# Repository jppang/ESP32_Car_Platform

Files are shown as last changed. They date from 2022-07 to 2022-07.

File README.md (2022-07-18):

# ESP32_Car_Platform
To design a four wheels Mecanum car platform controlled by Dabble App in Arduino and MicroPython.



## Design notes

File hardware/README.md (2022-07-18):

Hardware design of this ESP32 car platform is by using KiCad 6.



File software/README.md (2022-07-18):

To control the ESP32 Car, two methods are implemented, Arduino and MicroPython.

The implementation in Arduino is forked from one repo in the Net, communicates with one APP called Dabble.
https://www.instructables.com/ESP32-Mecanum-Wheels-Robot-and-Bluetooth-Gamepad-C/

The implementation in MicroPython is coded by myself based on the above example.

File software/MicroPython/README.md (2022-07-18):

MicroPython implementation is coded by myself by referencing Arduino example.

Basically, two files are needed, ble.py and main.py.

ble.py is the MicroPython library based on ubluetooth.

main.py is the controller code.

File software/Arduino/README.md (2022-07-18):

This file is basically a forked one, and just modified those pin assignments.

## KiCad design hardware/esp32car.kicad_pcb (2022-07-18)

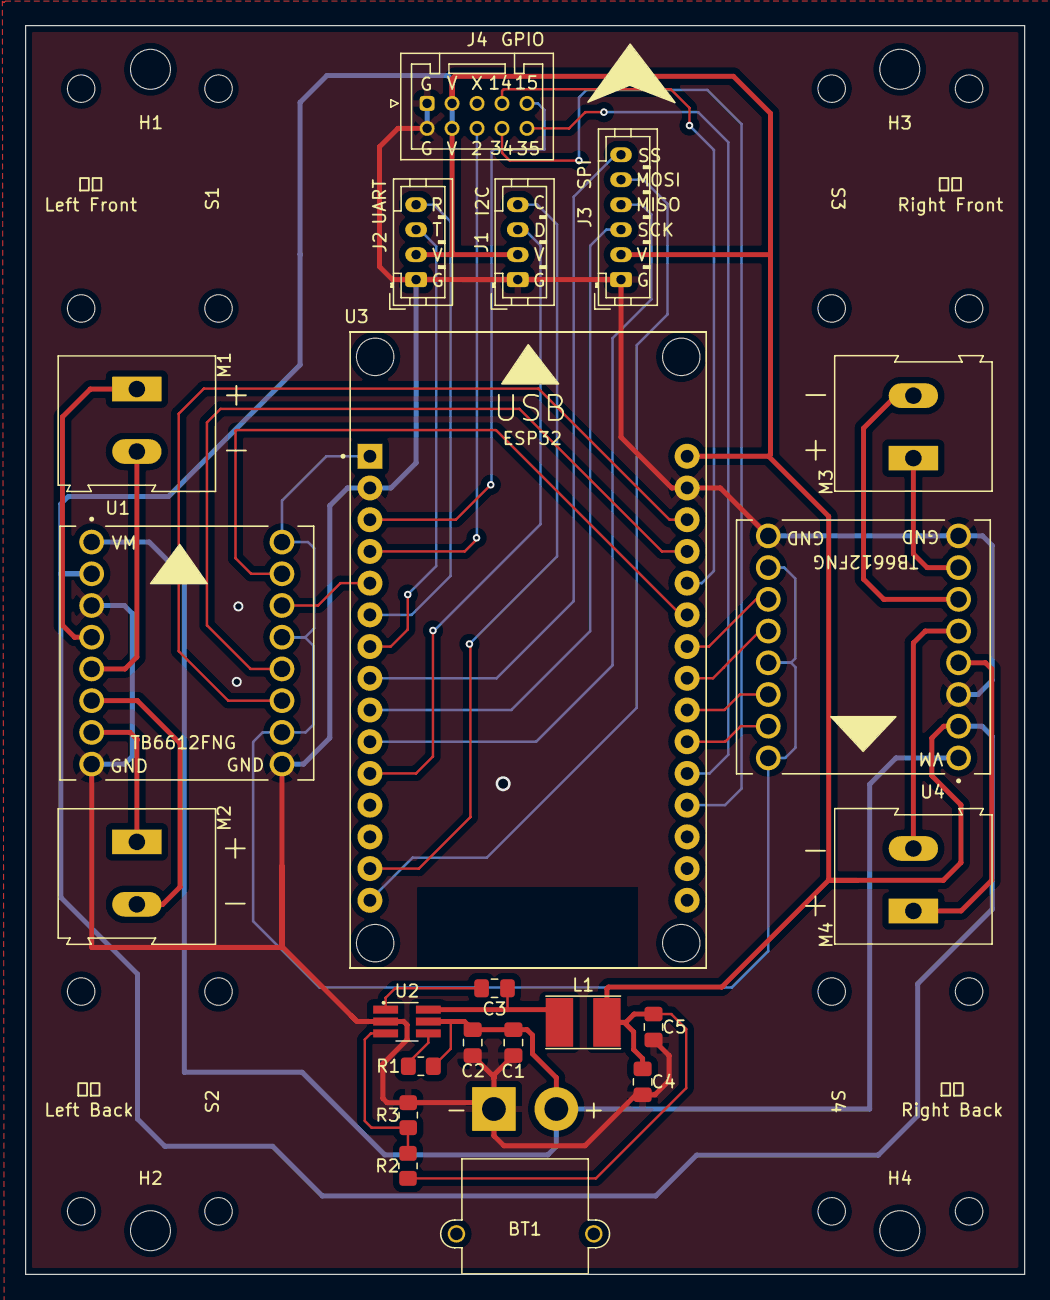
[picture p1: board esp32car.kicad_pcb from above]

Board: 2 copper layers, 80.0 x 100.0 mm, 30 parts (0 on the bottom side), 37 nets.

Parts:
BT1: 2or3S; AMASS_XT30PW-M_1x02_P2.50mm_Horizontal
C1, C5: 22uF; C_0805_2012Metric_Pad1.18x1.45mm_HandSolder
C2, C3, C4: 0.1uF; C_0805_2012Metric_Pad1.18x1.45mm_HandSolder
H1, H2, H3, H4: MountingHole; MountingHole_3.2mm_M3
J1: I2C; JST_PH_B4B-PH-K_1x04_P2.00mm_Vertical
J2: UART; JST_PH_B4B-PH-K_1x04_P2.00mm_Vertical
J3: SPI; JST_PH_B6B-PH-K_1x06_P2.00mm_Vertical
J4: GPIO; JST_PUD_B10B-PUDSS_2x05_P2.00mm_Vertical
L1: 3.3uH; L_Taiyo-Yuden_NR-40xx_HandSoldering
M1: LeftFront; TerminalBlock_Altech_AK300-2_P5.00mm
M2: LeftBack; TerminalBlock_Altech_AK300-2_P5.00mm
M3: RightFront; TerminalBlock_Altech_AK300-2_P5.00mm
M4: RightBack; TerminalBlock_Altech_AK300-2_P5.00mm
R1: 200K; R_0805_2012Metric_Pad1.20x1.40mm_HandSolder
R2: 24.6K; R_0805_2012Metric_Pad1.20x1.40mm_HandSolder
R3: 4.7K; R_0805_2012Metric_Pad1.20x1.40mm_HandSolder
S1, S2, S3, S4: Mounting_Jack_N20_Motor; MountingHole_N20_Motor_2.2mm_M2
U1: TB6612FNG-Left; MODULE_ROB-14450
U2: PW2312; TSOT-23-6_HandSoldering
U3: ESP32-DEVKIT-V1; MODULE_ESP32_DEVKIT_V1
U4: TB6612FNG-Right; MODULE_ROB-14450

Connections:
+3V3: U1.10 (PWMB), U1.13 (STBY), U1.16 (PWMA), U3.1 (3V3), U4.10 (PWMB), U4.13 (STBY), U4.16 (PWMA)
+5V: C4.1, C5.1, J1.2, J2.2, J3.2, J4.3, J4.4, L1.2, R2.1, U1.2 (VCC), U3.30 (VIN), U4.2 (VCC)
+BATT: BT1.2 (+), C1.1, C2.1, R1.1, U1.1 (VM), U2.5 (VIN), U4.1 (VM)
/2: J4.6, U3.4 (D2)
/14: J4.7, U3.26 (D14)
/15: J4.9, U3.3 (D15)
/34: J4.8, U3.19 (D34)
/35: J4.10, U3.20 (D35)
/LBBWD: U1.11 (BI2), U3.28 (D13)
/LBFWD: U1.12 (BI1), U3.27 (D12)
/LFBWD: U1.15 (AI2), U3.25 (D27)
/LFFWD: U1.14 (AI1), U3.5 (D4)
/LeftBackBWD: M2.2 (-), U1.6 (B02)
/LeftBackFWD: M2.1 (+), U1.7 (B01)
/LeftFrontBWD: M1.2 (-), U1.5 (A02)
/LeftFrontFWD: M1.1 (+), U1.4 (A01)
/MISO: J3.4, U3.10 (D19)
/MOSI: J3.5, U3.15 (D23)
/RBBWD: U3.21 (D32), U4.15 (AI2)
/RBFWD: U3.22 (D33), U4.14 (AI1)
/RFBWD: U3.24 (D26), U4.11 (BI2)
/RFFWD: U3.23 (D25), U4.12 (BI1)
/RX: J2.4, U3.6 (RX2)
/RightBackBWD: M4.2 (-), U4.5 (A02)
/RightBackFWD: M4.1 (+), U4.4 (A01)
/RightFrontBWD: M3.2 (-), U4.6 (B02)
/RightFrontFWD: M3.1 (+), U4.7 (B01)
/SCK: J3.3, U3.9 (D18)
/SCL: J1.4, U3.14 (D22)
/SDA: J1.3, U3.11 (D21)
/SS: J3.6, U3.8 (D5)
/TX: J2.3, U3.7 (TX2)
GND: BT1.1 (-), C1.2, C2.2, C4.2, C5.2, J1.1, J2.1, J3.1, J4.1, J4.2, R3.2, U1.3 (GND), U1.8 (GND), U1.9 (GND), U2.2 (GND), U3.2 (GND), U3.29 (GND), U4.3 (GND), U4.8 (GND), U4.9 (GND)
unnamed: C3.1, U2.1 (BS)
unnamed: C3.2, L1.1, U2.6 (SW)
unnamed: R1.2, U2.4 (EN)
unnamed: R2.2, R3.1, U2.3 (FB)

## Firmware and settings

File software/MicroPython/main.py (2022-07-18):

from machine import Pin
from ble import BLE

RightFrontFWD = 26
RightFrontBWD = 25
RightBackFWD = 32
RightBackBWD = 33

LeftFrontFWD = 4
LeftFrontBWD = 27
LeftBackFWD = 12
LeftBackBWD = 13

#Dabble App message is consisted of 8 bytes, and those commands associated with GamePad are in the combination of
#6th and 7th bytes of this message.
UP = b'\x00\x01'
DOWN = b'\x00\x02'
LEFT = b'\x00\x04'
RIGHT = b'\x00\x08'
TRIANGLE = b'\x04\x00'
CROSS = b'\x10\x00'
SQUARE = b' \x00'
CIRCLE = b'\x08\x00'
SELECT = b'\x02\x00'
START = b'\x01\x00'

mode = bytearray()

rfFWD = Pin(RightFrontFWD, Pin.OUT)
rfBWD = Pin(RightFrontBWD, Pin.OUT)
rbFWD = Pin(RightBackFWD, Pin.OUT)
rbBWD = Pin(RightBackBWD, Pin.OUT)
lfFWD = Pin(LeftFrontFWD, Pin.OUT)
lfBWD = Pin(LeftFrontBWD, Pin.OUT)
lbFWD = Pin(LeftBackFWD, Pin.OUT)
lbBWD = Pin(LeftBackBWD, Pin.OUT)

def moveForward():
    rfFWD.on()
    rfBWD.off()
    rbFWD.on()
    rbBWD.off()

    lfFWD.on()
    lfBWD.off()
    lbFWD.on()
    lbBWD.off()

def moveBackward():
    rfFWD.off()
    rfBWD.on()
    rbFWD.off()
    rbBWD.on()

    lfFWD.off()
    lfBWD.on()
    lbFWD.off()
    lbBWD.on()

def rotateRight():
    rfFWD.off()
    rfBWD.on()
    rbFWD.off()
    rbBWD.on()

    lfFWD.on()
    lfBWD.off()
    lbFWD.on()
    lbBWD.off()

def rotateLeft():
    rfFWD.on()
    rfBWD.off()
    rbFWD.on()
    rbBWD.off()

    lfFWD.off()
    lfBWD.on()
    lbFWD.off()
    lbBWD.on()

def moveSidewaysRight():
    rfFWD.off()
    rfBWD.on()
    rbFWD.on()
    rbBWD.off()

    lfFWD.on()
    lfBWD.off()
    lbFWD.off()
    lbBWD.on()

def moveSidewaysLeft():
    rfFWD.on()
    rfBWD.off()
    rbFWD.off()
    rbBWD.on()

    lfFWD.off()
    lfBWD.on()
    lbFWD.on()
    lbBWD.off()

def moveRightForward():
    rfFWD.off()
    rfBWD.off()
    rbFWD.on()
    rbBWD.off()

    lfFWD.on()
    lfBWD.off()
    lbFWD.off()
    lbBWD.off()

def moveLeftForward():
    rfFWD.on()
    rfBWD.off()
    rbFWD.off()
    rbBWD.off()

    lfFWD.off()
    lfBWD.off()
    lbFWD.on()
    lbBWD.off()

def stopMoving():
    rfFWD.off()
    rfBWD.off()
    rbFWD.off()
    rbBWD.off()

    lfFWD.off()
    lfBWD.off()
    lbFWD.off()
    lbBWD.off()

ble = BLE()

while(True):
    if ble.flag == True:
        mode = ble.message[5:7]
        print(mode)
        ble.flag = False

        if mode == UP:
            print("UP is pressed.")
            moveForward()
        elif mode == DOWN:
            print("DOWN is pressed.")
            moveBackward()
        elif mode == LEFT:
            print("LEFT is pressed.")
            rotateLeft()
        elif mode == RIGHT:
            print("RIGHT is pressed.")
            rotateRight()
        elif mode == TRIANGLE:
            print("TRIANGLE is pressed.")
            moveLeftForward()
        elif mode == CROSS:
            print("CROSS is pressed.")
            moveRightForward()
        elif mode == SQUARE:
            print("SQUARE is pressed.")
            moveSidewaysLeft()
        elif mode == CIRCLE:
            print("CIRCLE is pressed.")
            moveSidewaysRight()
        elif mode == SELECT:
            print("SELECT is pressed.")
        elif mode == START:
            print("START is pressed.")
        else:
            stopMoving()

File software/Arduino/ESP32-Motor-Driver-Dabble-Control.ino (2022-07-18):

#define CUSTOM_SETTINGS
#define INCLUDE_GAMEPAD_MODULE
#include <DabbleESP32.h>

#include <Arduino.h>

#define RightFrontFWD 26
#define RightFrontBWD 25
#define RightBackFWD 32
#define RightBackBWD 33

#define LeftFrontFWD 4
#define LeftFrontBWD 27
#define LeftBackFWD 12
#define LeftBackBWD 13

void setup() {
  pinMode(RightFrontFWD, OUTPUT);
  pinMode(RightFrontBWD, OUTPUT);
  pinMode(RightBackFWD, OUTPUT);
  pinMode(RightBackBWD, OUTPUT);
  pinMode(LeftFrontFWD, OUTPUT);
  pinMode(LeftFrontBWD, OUTPUT);
  pinMode(LeftBackFWD, OUTPUT);
  pinMode(LeftBackBWD, OUTPUT);
  // put your setup code here, to run once:
  Serial.begin(115200);      // make sure your Serial Monitor is also set at this baud rate.
  Dabble.begin("MyEsp32");       //set bluetooth name of your device
}

void loop() {
  Dabble.processInput();//this function is used to refresh data obtained from smartphone.Hence calling this function is mandatory in order to get data properly from your mobile.
  Serial.print("KeyPressed: ");
  if (GamePad.isUpPressed())
  {
    Serial.print("Up");
    moveForward();
  } else if (GamePad.isDownPressed())
  {
    Serial.print("Down");
    moveBackward();
  } else if (GamePad.isLeftPressed())
  {
    Serial.print("Left");
    rotateLeft();
  } else if (GamePad.isRightPressed())
  {
    Serial.print("Right");
    rotateRight();
  } else if (GamePad.isSquarePressed())
  {
    Serial.print("Square");
    moveSidewaysRight();
  } else if (GamePad.isCirclePressed())
  {
    Serial.print("Circle");
    moveSidewaysLeft();
  } else if (GamePad.isCrossPressed())
  {
    Serial.print("Cross");
    moveRightForward();
  } else if (GamePad.isTrianglePressed())
  {
    Serial.print("Triangle");
    moveLeftForward();
  } else
  {
    stopMoving();
  }

  /*if (GamePad.isStartPressed())
    {
    Serial.print("Start");
    }

    if (GamePad.isSelectPressed())
    {
    Serial.print("Select");
    } */
  Serial.print('\t');

  int a = GamePad.getAngle();
  Serial.print("Angle: ");
  Serial.print(a);
  Serial.print('\t');
  int b = GamePad.getRadius();
  Serial.print("Radius: ");
  Serial.print(b);
  Serial.print('\t');
  float c = GamePad.getXaxisData();
  Serial.print("x_axis: ");
  Serial.print(c);
  Serial.print('\t');
  float d = GamePad.getYaxisData();
  Serial.print("y_axis: ");
  Serial.println(d);
  Serial.println();
}

void moveForward() {
  digitalWrite(RightFrontFWD, HIGH);
  digitalWrite(RightFrontBWD, LOW);
  digitalWrite(RightBackFWD, HIGH);
  digitalWrite(RightBackBWD, LOW);

  digitalWrite(LeftFrontFWD, HIGH);
  digitalWrite(LeftFrontBWD, LOW);
  digitalWrite(LeftBackFWD, HIGH);
  digitalWrite(LeftBackBWD, LOW);
}

void moveBackward() {
  digitalWrite(RightFrontFWD, LOW);
  digitalWrite(RightFrontBWD, HIGH);
  digitalWrite(RightBackFWD, LOW);
  digitalWrite(RightBackBWD, HIGH);

  digitalWrite(LeftFrontFWD, LOW);
  digitalWrite(LeftFrontBWD, HIGH);
  digitalWrite(LeftBackFWD, LOW);
  digitalWrite(LeftBackBWD, HIGH);
}

void rotateRight() {
  digitalWrite(RightFrontFWD, LOW);
  digitalWrite(RightFrontBWD, HIGH);
  digitalWrite(RightBackFWD, LOW);
  digitalWrite(RightBackBWD, HIGH);

  digitalWrite(LeftFrontFWD, HIGH);
  digitalWrite(LeftFrontBWD, LOW);
  digitalWrite(LeftBackFWD, HIGH);
  digitalWrite(LeftBackBWD, LOW);
}

void rotateLeft() {
  digitalWrite(RightFrontFWD, HIGH);
  digitalWrite(RightFrontBWD, LOW);
  digitalWrite(RightBackFWD, HIGH);
  digitalWrite(RightBackBWD, LOW);

  digitalWrite(LeftFrontFWD, LOW);
  digitalWrite(LeftFrontBWD, HIGH);
  digitalWrite(LeftBackFWD, LOW);
  digitalWrite(LeftBackBWD, HIGH);
}

void moveSidewaysRight() {
  digitalWrite(RightFrontFWD, LOW);
  digitalWrite(RightFrontBWD, HIGH);
  digitalWrite(RightBackFWD, HIGH);
  digitalWrite(RightBackBWD, LOW);

  digitalWrite(LeftFrontFWD, HIGH);
  digitalWrite(LeftFrontBWD, LOW);
  digitalWrite(LeftBackFWD, LOW);
  digitalWrite(LeftBackBWD, HIGH);
}

void moveSidewaysLeft() {
  digitalWrite(RightFrontFWD, HIGH);
  digitalWrite(RightFrontBWD, LOW);
  digitalWrite(RightBackFWD, LOW);
  digitalWrite(RightBackBWD, HIGH);

  digitalWrite(LeftFrontFWD, LOW);
  digitalWrite(LeftFrontBWD, HIGH);
  digitalWrite(LeftBackFWD, HIGH);
  digitalWrite(LeftBackBWD, LOW);
}

void moveRightForward() {
  digitalWrite(RightFrontFWD, LOW);
  digitalWrite(RightFrontBWD, LOW);
  digitalWrite(RightBackFWD, HIGH);
  digitalWrite(RightBackBWD, LOW);

  digitalWrite(LeftFrontFWD, HIGH);
  digitalWrite(LeftFrontBWD, LOW);
  digitalWrite(LeftBackFWD, LOW);
  digitalWrite(LeftBackBWD, LOW);
}

void moveLeftForward() {
  digitalWrite(RightFrontFWD, HIGH);
  digitalWrite(RightFrontBWD, LOW);
  digitalWrite(RightBackFWD, LOW);
  digitalWrite(RightBackBWD, LOW);

  digitalWrite(LeftFrontFWD, LOW);
  digitalWrite(LeftFrontBWD, LOW);
  digitalWrite(LeftBackFWD, HIGH);
  digitalWrite(LeftBackBWD, LOW);
}

void stopMoving() {
  digitalWrite(RightFrontFWD, LOW);
  digitalWrite(RightFrontBWD, LOW);
  digitalWrite(RightBackFWD, LOW);
  digitalWrite(RightBackBWD, LOW);

  digitalWrite(LeftFrontFWD, LOW);
  digitalWrite(LeftFrontBWD, LOW);
  digitalWrite(LeftBackFWD, LOW);
  digitalWrite(LeftBackBWD, LOW);
}
